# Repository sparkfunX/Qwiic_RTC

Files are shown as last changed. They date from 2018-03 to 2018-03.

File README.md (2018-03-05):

SparkFun Qwiic Real Time Clock
========================================

SparkFun Qwiic RTC Breakout

[*SparkFun Qwiic RTC (SPX-14642)*](https://www.sparkfun.com/products/14642)

The Qwiic-RTC from SparkFun is a very unique and exciting Real Time Clock. It is extremely precise (within 3 minutes over a year!), extremely low power (less than 22nA!) and has all the necessary oscillators built-in making it very compact.

The RV-1805 has not one, but two internal oscillators: a 32.768kHz tuning fork crystal and a low power RC based oscillator. The RV-1805 automatically switches between oscillators using the more precise crystal to correct the RC oscillator every few minutes. This allows the RTC to maintain a very accurate date and time with the worst case being +/- about 3 minutes over a year. Very few RTCs can come close to this.

The RV-1805 and the library we've written operate the RTC at 22nA. This is *extremely* low power. No external battery needed! We've included a 0.22F super cap on the Qwiic RTC. This *should* maintain the RTC for over 170 days (nearly 6 months) but we have not had 6 months to test this. For now, we guarantee the super cap will maintain the RTC for over a month. That means you can let board sit with no power or connection to the outside world and the current hour/minute/second/date will be maintained. The RV-1805 RTC has a built in trickle charger: as soon as the RTC is connected to power the super cap will begin to charge and will be fully charged in under 10 minutes. A super cap is superior to coin cells that cannot be charged.

The RV-1805 has an alarm and timer capability. This allows the user to set various alarms and generate interrupts when a certain time is achieved.

Lastly, and perhaps most interestingly the RV-1805 has the ability to switch power to other systems. The RV-1805 has a PSW pin that can sink up to 50mA. This allows it to *directly* turn on or off a power hungry device such as a microcontroller or RF engine. The RV-1805 can be configured to power up/down the device based on time or external interrupts.

The Qwiic-RTC uses the simple [Qwiic](https://www.sparkfun.com/qwiic) interface. No soldering, no voltage translation, no figuring out which pin is SDA, just plug and go!

The [SparkFun RV-1805 Arduino Library](https://github.com/sparkfun/SparkFun_RV-1805_Arduino_Library) contains a number of examples to show how to set and read the date and time from the RTC

Repository Contents
-------------------

* **/Documents** - Datasheets for the RV-1805-C3 and super capacitor
* **/Hardware** - Eagle design files (.brd, .sch)

License Information
-------------------

This product is _**open source**_! 

Please review the LICENSE.md file for license information. 

If you have any questions or concerns on licensing, please contact techsupport@sparkfun.com.

Please use, reuse, and modify these files as you see fit. Please maintain attribution to SparkFun Electronics and release any derivative under the same license.

Distributed as-is; no warranty is given.

- Your friends at SparkFun.

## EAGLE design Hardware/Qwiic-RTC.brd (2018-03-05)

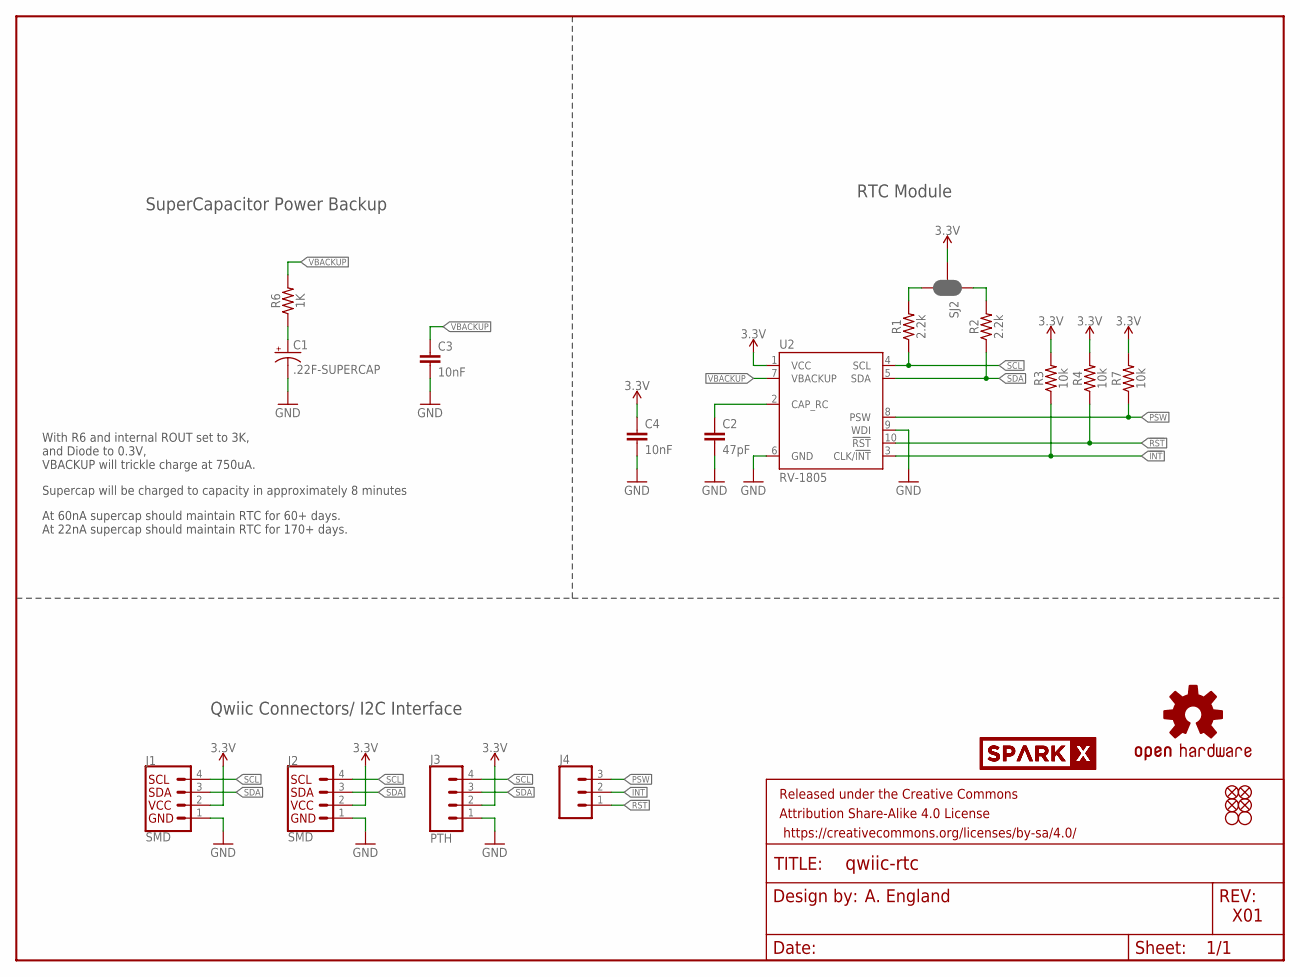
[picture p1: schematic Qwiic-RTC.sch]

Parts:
C1: .22F-SUPERCAP; DSK-RADIAL-6.8MM
C2: 47pF; 0603
C3, C4: 10nF; 0603
FD1, FD2, FD3, FD4: FIDUCIALUFIDUCIAL; FIDUCIAL-MICRO
FRAME2: FRAME-LETTER; CREATIVE_COMMONS
J1, J2: SMD; 1X04_1MM_RA
J3: PTH; 1X04_NO_SILK
J4: CONN_031X03_NO_SILK; 1X03_NO_SILK
LOGO1: OSHW-LOGOS; OSHW-LOGO-S
R1, R2: 2.2k; 0603
R3, R4, R7: 10k; 0603
R6: 1K; 0603
SJ2: JUMPER-SMT_3_2-NC_PASTE_SILK; SMT-JUMPER_3_2-NC_PASTE_SILK
U2: RV-1805
U$3, U$5: SPARKX-LOGO4; SPARKX-MEDIUM
U$6, U$7: STAND-OFF

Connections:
3.3V: C4.1, J1.2, J2.2, J3.2, R3.2, R4.2, R7.2, SJ2.2, U2.1 (VCC)
!INT: J4.2, R3.1, U2.3 (CLK/!INT)
!RST: J4.1, R4.1, U2.10 (!RST)
GND: C1.-, C2.2, C3.2, C4.2, J1.1, J2.1, J3.1, U2.6 (GND), U2.9 (WDI)
unnamed: R1.2, SJ2.3
unnamed: R2.2, SJ2.1
unnamed: C2.1, U2.2 (CAP_RC)
unnamed: C1.+, R6.1
PSW: J4.3, R7.1, U2.8 (PSW)
SCL: J1.4, J2.4, J3.4, R1.1, U2.4 (SCL)
SDA: J1.3, J2.3, J3.3, R2.1, U2.5 (SDA)
VBACKUP: C3.1, R6.2, U2.7 (VBACKUP)

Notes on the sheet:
X01
A. England
SuperCapacitor Power Backup
RTC Module
Qwiic Connectors/ I2C Interface
With R6 and internal ROUT set to 3K, and Diode to 0.3V, VBACKUP will trickle charge at 750uA.
Supercap will be charged to capacity in approximately 8 minutes
At 60nA supercap should maintain RTC for 60+ days. At 22nA supercap should maintain RTC for 170+ days.

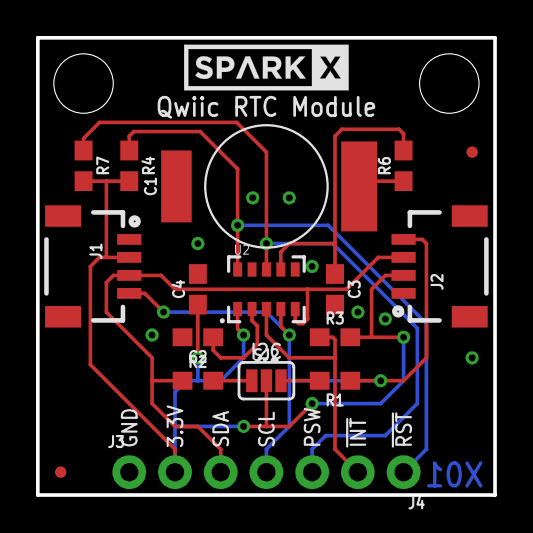
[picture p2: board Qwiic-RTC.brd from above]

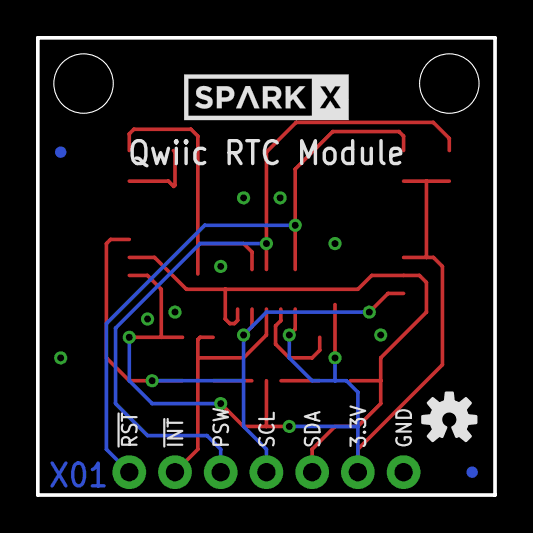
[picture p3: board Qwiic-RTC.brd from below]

Board: 2 copper layers, 25.4 x 25.4 mm, 26 parts (4 on the bottom side), 12 nets.

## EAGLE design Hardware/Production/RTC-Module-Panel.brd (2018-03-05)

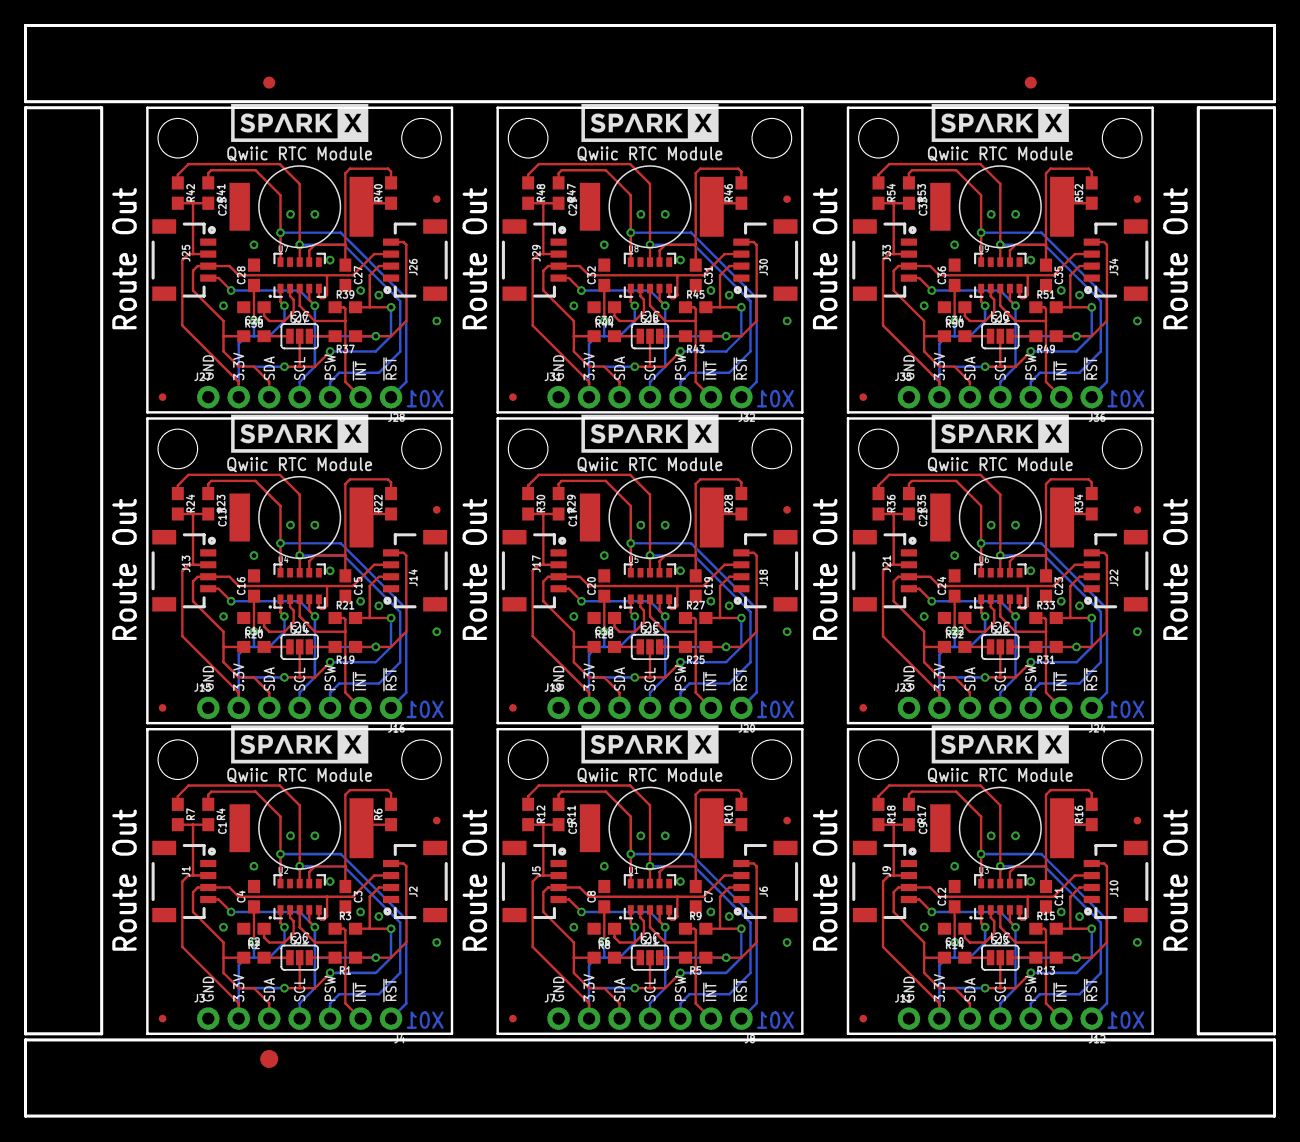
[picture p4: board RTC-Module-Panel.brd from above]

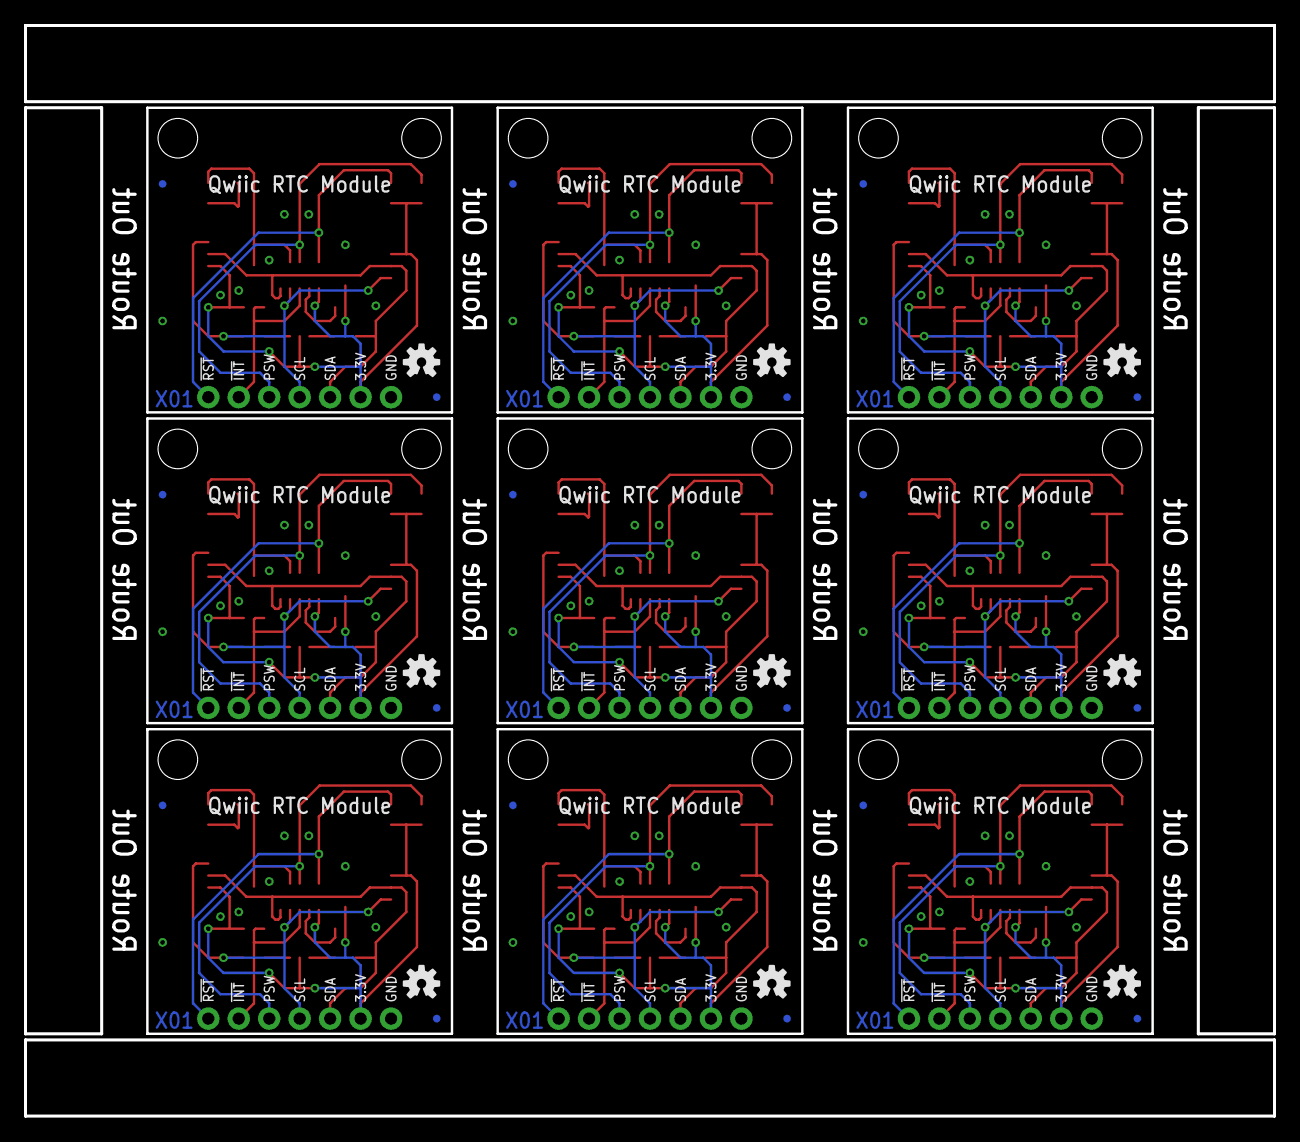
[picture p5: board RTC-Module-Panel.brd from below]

Board: 2 copper layers, 104.1 x 90.9 mm, 219 parts (27 on the bottom side), 108 nets.

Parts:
C1, C5, C9, C13, C17, C21, C25, C29, C33: .22F-SUPERCAP; DSK-RADIAL-6.8MM
C2, C6, C10, C14, C18, C22, C26, C30, C34: 47pF; 0603
C3, C4, C7, C8, C11, C12, C15, C16, C19, C20, C23, C24, C27, C28, C31, C32, C35, C36: 10nF; 0603
E$1, E$2: FIDUCIAL-1X2
E$3: FIDUCIAL-1.5X3
FD1, FD2, FD3, FD4, FD5, FD6, FD7, FD8, FD9, FD10, FD11, FD12, FD13, FD14, FD15, FD16, FD17, FD18, FD19, FD20, FD21, FD22, FD23, FD24, FD25, FD26, FD27, FD28, FD29, FD30, FD31, FD32, FD33, FD34, FD35, FD36: FIDUCIALUFIDUCIAL; FIDUCIAL-MICRO
J1, J2, J5, J6, J9, J10, J13, J14, J17, J18, J21, J22, J25, J26, J29, J30, J33, J34: SMD; 1X04_1MM_RA
J3, J7, J11, J15, J19, J23, J27, J31, J35: PTH; 1X04_NO_SILK
J4, J8, J12, J16, J20, J24, J28, J32, J36: 1X03_NO_SILK
LOGO1, LOGO2, LOGO3, LOGO4, LOGO5, LOGO6, LOGO7, LOGO8, LOGO9: OSHW-LOGOS; OSHW-LOGO-S
R1, R2, R5, R8, R13, R14, R19, R20, R25, R26, R31, R32, R37, R38, R43, R44, R49, R50: 2.2k; 0603
R3, R4, R7, R9, R11, R12, R15, R17, R18, R21, R23, R24, R27, R29, R30, R33, R35, R36, R39, R41, R42, R45, R47, R48, R51, R53, R54: 10k; 0603
R6, R10, R16, R22, R28, R34, R40, R46, R52: 1K; 0603
SJ1, SJ2, SJ3, SJ4, SJ5, SJ6, SJ7, SJ8, SJ9: JUMPER-SMT_3_2-NC_PASTE_SILK; SMT-JUMPER_3_2-NC_PASTE_SILK
U1, U2, U3, U4, U5, U6, U7, U8, U9: RV-1805
U$1, U$4, U$9, U$12, U$15, U$18, U$21, U$24, U$27: SPARKX-LOGO5; SPARKX-LARGE
U$2, U$3, U$5, U$6, U$7, U$8, U$10, U$11, U$13, U$14, U$16, U$17, U$19, U$20, U$22, U$23, U$25, U$26: STAND-OFF

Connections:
3.3V: C4.1, J1.2, J2.2, J3.2, R3.2, R4.2, R7.2, SJ2.2, U2.1
3.3V1: C8.1, J5.2, J6.2, J7.2, R9.2, R11.2, R12.2, SJ1.2, U1.1
3.3V2: C12.1, J9.2, J10.2, J11.2, R15.2, R17.2, R18.2, SJ3.2, U3.1
3.3V3: C16.1, J13.2, J14.2, J15.2, R21.2, R23.2, R24.2, SJ4.2, U4.1
3.3V4: C20.1, J17.2, J18.2, J19.2, R27.2, R29.2, R30.2, SJ5.2, U5.1
3.3V5: C24.1, J21.2, J22.2, J23.2, R33.2, R35.2, R36.2, SJ6.2, U6.1
3.3V6: C28.1, J25.2, J26.2, J27.2, R39.2, R41.2, R42.2, SJ7.2, U7.1
3.3V7: C32.1, J29.2, J30.2, J31.2, R45.2, R47.2, R48.2, SJ8.2, U8.1
3.3V8: C36.1, J33.2, J34.2, J35.2, R51.2, R53.2, R54.2, SJ9.2, U9.1
!INT: J4.2, R3.1, U2.3
!INT1: J8.2, R9.1, U1.3
!INT2: J12.2, R15.1, U3.3
!INT3: J16.2, R21.1, U4.3
!INT4: J20.2, R27.1, U5.3
!INT5: J24.2, R33.1, U6.3
!INT6: J28.2, R39.1, U7.3
!INT7: J32.2, R45.1, U8.3
!INT8: J36.2, R51.1, U9.3
!RST: J4.1, R4.1, U2.10
!RST1: J8.1, R11.1, U1.10
!RST2: J12.1, R17.1, U3.10
!RST3: J16.1, R23.1, U4.10
!RST4: J20.1, R29.1, U5.10
!RST5: J24.1, R35.1, U6.10
!RST6: J28.1, R41.1, U7.10
!RST7: J32.1, R47.1, U8.10
!RST8: J36.1, R53.1, U9.10
GND: C1.-, C2.2, C3.2, C4.2, J1.1, J2.1, J3.1, U2.6, U2.9
GND1: C5.-, C6.2, C7.2, C8.2, J5.1, J6.1, J7.1, U1.6, U1.9
GND2: C9.-, C10.2, C11.2, C12.2, J9.1, J10.1, J11.1, U3.6, U3.9
GND3: C13.-, C14.2, C15.2, C16.2, J13.1, J14.1, J15.1, U4.6, U4.9
GND4: C17.-, C18.2, C19.2, C20.2, J17.1, J18.1, J19.1, U5.6, U5.9
GND5: C21.-, C22.2, C23.2, C24.2, J21.1, J22.1, J23.1, U6.6, U6.9
GND6: C25.-, C26.2, C27.2, C28.2, J25.1, J26.1, J27.1, U7.6, U7.9
GND7: C29.-, C30.2, C31.2, C32.2, J29.1, J30.1, J31.1, U8.6, U8.9
GND8: C33.-, C34.2, C35.2, C36.2, J33.1, J34.1, J35.1, U9.6, U9.9
unnamed: R1.2, SJ2.3
unnamed: R2.2, SJ2.1
unnamed: R5.2, SJ1.3
unnamed: C2.1, U2.2
unnamed: C1.+, R6.1
unnamed: R8.2, SJ1.1
unnamed: C6.1, U1.2
unnamed: C5.+, R10.1
unnamed: R13.2, SJ3.3
unnamed: R14.2, SJ3.1
unnamed: C10.1, U3.2
unnamed: C9.+, R16.1
unnamed: R19.2, SJ4.3
unnamed: R20.2, SJ4.1
unnamed: C14.1, U4.2
unnamed: C13.+, R22.1
unnamed: R25.2, SJ5.3
unnamed: R26.2, SJ5.1
unnamed: C18.1, U5.2
unnamed: C17.+, R28.1
unnamed: R31.2, SJ6.3
unnamed: R32.2, SJ6.1
unnamed: C22.1, U6.2
unnamed: C21.+, R34.1
unnamed: R37.2, SJ7.3
unnamed: R38.2, SJ7.1
unnamed: C26.1, U7.2
unnamed: C25.+, R40.1
unnamed: R43.2, SJ8.3
unnamed: R44.2, SJ8.1
unnamed: C30.1, U8.2
unnamed: C29.+, R46.1
unnamed: R49.2, SJ9.3
unnamed: R50.2, SJ9.1
unnamed: C34.1, U9.2
unnamed: C33.+, R52.1
PSW: J4.3, R7.1, U2.8
PSW1: J8.3, R12.1, U1.8
PSW2: J12.3, R18.1, U3.8
PSW3: J16.3, R24.1, U4.8
PSW4: J20.3, R30.1, U5.8
PSW5: J24.3, R36.1, U6.8
PSW6: J28.3, R42.1, U7.8
PSW7: J32.3, R48.1, U8.8
PSW8: J36.3, R54.1, U9.8
SCL: J1.4, J2.4, J3.4, R1.1, U2.4
SCL1: J5.4, J6.4, J7.4, R5.1, U1.4
SCL2: J9.4, J10.4, J11.4, R13.1, U3.4
SCL3: J13.4, J14.4, J15.4, R19.1, U4.4
SCL4: J17.4, J18.4, J19.4, R25.1, U5.4
SCL5: J21.4, J22.4, J23.4, R31.1, U6.4
SCL6: J25.4, J26.4, J27.4, R37.1, U7.4
SCL7: J29.4, J30.4, J31.4, R43.1, U8.4
SCL8: J33.4, J34.4, J35.4, R49.1, U9.4
SDA: J1.3, J2.3, J3.3, R2.1, U2.5
SDA1: J5.3, J6.3, J7.3, R8.1, U1.5
SDA2: J9.3, J10.3, J11.3, R14.1, U3.5
SDA3: J13.3, J14.3, J15.3, R20.1, U4.5
SDA4: J17.3, J18.3, J19.3, R26.1, U5.5
SDA5: J21.3, J22.3, J23.3, R32.1, U6.5
SDA6: J25.3, J26.3, J27.3, R38.1, U7.5
SDA7: J29.3, J30.3, J31.3, R44.1, U8.5
SDA8: J33.3, J34.3, J35.3, R50.1, U9.5
VBACKUP: C3.1, R6.2, U2.7
VBACKUP1: C7.1, R10.2, U1.7
VBACKUP2: C11.1, R16.2, U3.7
VBACKUP3: C15.1, R22.2, U4.7
VBACKUP4: C19.1, R28.2, U5.7
VBACKUP5: C23.1, R34.2, U6.7
VBACKUP6: C27.1, R40.2, U7.7
VBACKUP7: C31.1, R46.2, U8.7
VBACKUP8: C35.1, R52.2, U9.7

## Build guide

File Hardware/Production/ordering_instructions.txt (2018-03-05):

board size, 105x91mm
board thickness, 0.8mm
number of layers, 2
soldermask color, Black
silkscreen color, white
oz copper, 1oz
finish, HASL lead free

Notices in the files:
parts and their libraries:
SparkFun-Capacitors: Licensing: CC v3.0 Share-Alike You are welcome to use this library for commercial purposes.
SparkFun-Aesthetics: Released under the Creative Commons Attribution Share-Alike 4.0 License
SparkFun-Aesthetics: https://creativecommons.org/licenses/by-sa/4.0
